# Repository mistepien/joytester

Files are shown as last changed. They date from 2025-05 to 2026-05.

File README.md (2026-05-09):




# joytester
Joytester for testing of Atari-like+ joysticks

Joytester for testing Atari-like joysticks -- tests also FIRE2 nd FIRE3 in C64 and Amiga/Atari mode.

More about Amiga/Atari and C64 modes: <a href="https://wiki.icomp.de/wiki/File:JoystickMod.jpg">schematic of universal joystick</a>.

<b>Populate only one of U1 or U2, never both!</b>

SW3 is redundand.

You can use the <a href="https://github.com/mistepien/joytester/tree/main/production">gerber file</a> to order the PCB.

Here you have <a href="https://github.com/mistepien/joytester/blob/main/joytester.pdf
">the schematic file</a> to find out how does it work.

BOM:
| Qty	| Reference(s) | Description |
|-----|---|---|
|10 | D1, D2, D3, D4, D5, D6, D7, D8, D9, D10 | LEDs 3mm |  
|10 | R1, R2, R3, R4, R5, R6, R7, R8, R9, R10 | resisors for D1...D10 |
|3 | R11, R12, R13 | 10KΩ pull-up/pull-down resistors |
| 2 | R14, R15 | 5K1Ω resistors for J3 USB C power-only socket |
|1 | J1| DB9 Male Connector ( eg. <a href="https://www.tme.eu/pl/en/details/ld09p13a4gx00lf/d-sub-plugs-and-sockets/amphenol-communications-solutions/">LD09P13A4GX00LF Amphenol</a>) |
|1 | J2 | USB B socket |
|1 | J3 | USB C power-only socket (eg.  <a href="https://www.tme.eu/pl/en/details/usb4125-gf-a/usb-ieee1394-connectors/gct/">USB4125-GF-A GCT</a> ) |
|1 | J4 | USB B Mini socket |
|1 | J5 | USB B Micro socket |
|1 | U1 | DIP14 socket (width 7.62mm) + 4070 IC or 4030 IC XOR Gates|
|1 | U2 | DIP14 socket (width 7.62mm) + 74HC86 IC XOR Gates |
|2| C1, C2 | decoupling capacitors for U2 | 
|2| C3, C4 | decoupling capacitors for U1 | 
|2 | SW1, SW2 | SPDT switches or 3x1 2.54mm pinheaders |
|1 | SW3 | SPDT switch, terminal pitch: 4.7mm |

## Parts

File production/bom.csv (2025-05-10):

Designator | Footprint | Quantity | Value | LCSC Part #
C1, C2, C3, C4 | C_Disc_D3.8mm_W2.6mm_P2.50mm | 4 | 100nF
D1 | LED_D3.0mm_Oval | 1 | C64
D10 | LED_D3.0mm_Oval | 1 | AMIGA
D2 | LED_D3.0mm_Oval | 1 | RIGHT
D3 | LED_D3.0mm_Oval | 1 | UP
D4 | LED_D3.0mm_Oval | 1 | DOWN
D5 | LED_D3.0mm_Oval | 1 | FIRE1
D6 | LED_D3.0mm_Oval | 1 | STATUS
D7 | LED_D3.0mm_Oval | 1 | LEFT
D8 | LED_D3.0mm_Oval | 1 | FIRE2
D9 | LED_D3.0mm_Oval | 1 | FIRE3
J1 | DSUB-9_Male_Horizontal_P2.77x2.84mm_EdgePinOffset7.70mm_Housed_MountingHolesOffset9.12mm | 1 | DB9_Male
J2 | USB_B_Lumberg_2411_02_Horizontal_Oval_Versatile | 1 | USB_B
J3 | GCT_USB4125-GF-A | 1 | USB_C_Receptacle_PowerOnly_6P
J4 | UBM5BRDM144DLFSNL | 1 | USB_B_Mini
J5 | USB_Micro-B_Amphenol_10118194_Horizontal | 1 | USB_B_Micro
R1, R10, R2, R3, R4, R5, R6, R7, R8, R9 | R_Axial_DIN0207_L6.3mm_D2.5mm_P10.16mm_Horizontal_Oval | 10 | RxΩ
R11, R12, R13 | R_Axial_DIN0207_L6.3mm_D2.5mm_P10.16mm_Horizontal_Oval | 3 | R10KΩ
R14, R15 | R_Axial_DIN0207_L6.3mm_D2.5mm_P10.16mm_Horizontal_Oval | 2 | R5K1Ω
SW1 | E-Switch-EG1218-Manufacturer_Recommended_Oval | 1 | C64MODESW
SW2 | E-Switch-EG1218-Manufacturer_Recommended_Oval | 1 | POWER
SW3 | 100SP1T1B4M2QE | 1 | POWER
U1 | DIP-14_W7.62mm_Socket_LongPads | 1 | 4070
U2 | DIP-14_W7.62mm_Socket_LongPads | 1 | 74HC86

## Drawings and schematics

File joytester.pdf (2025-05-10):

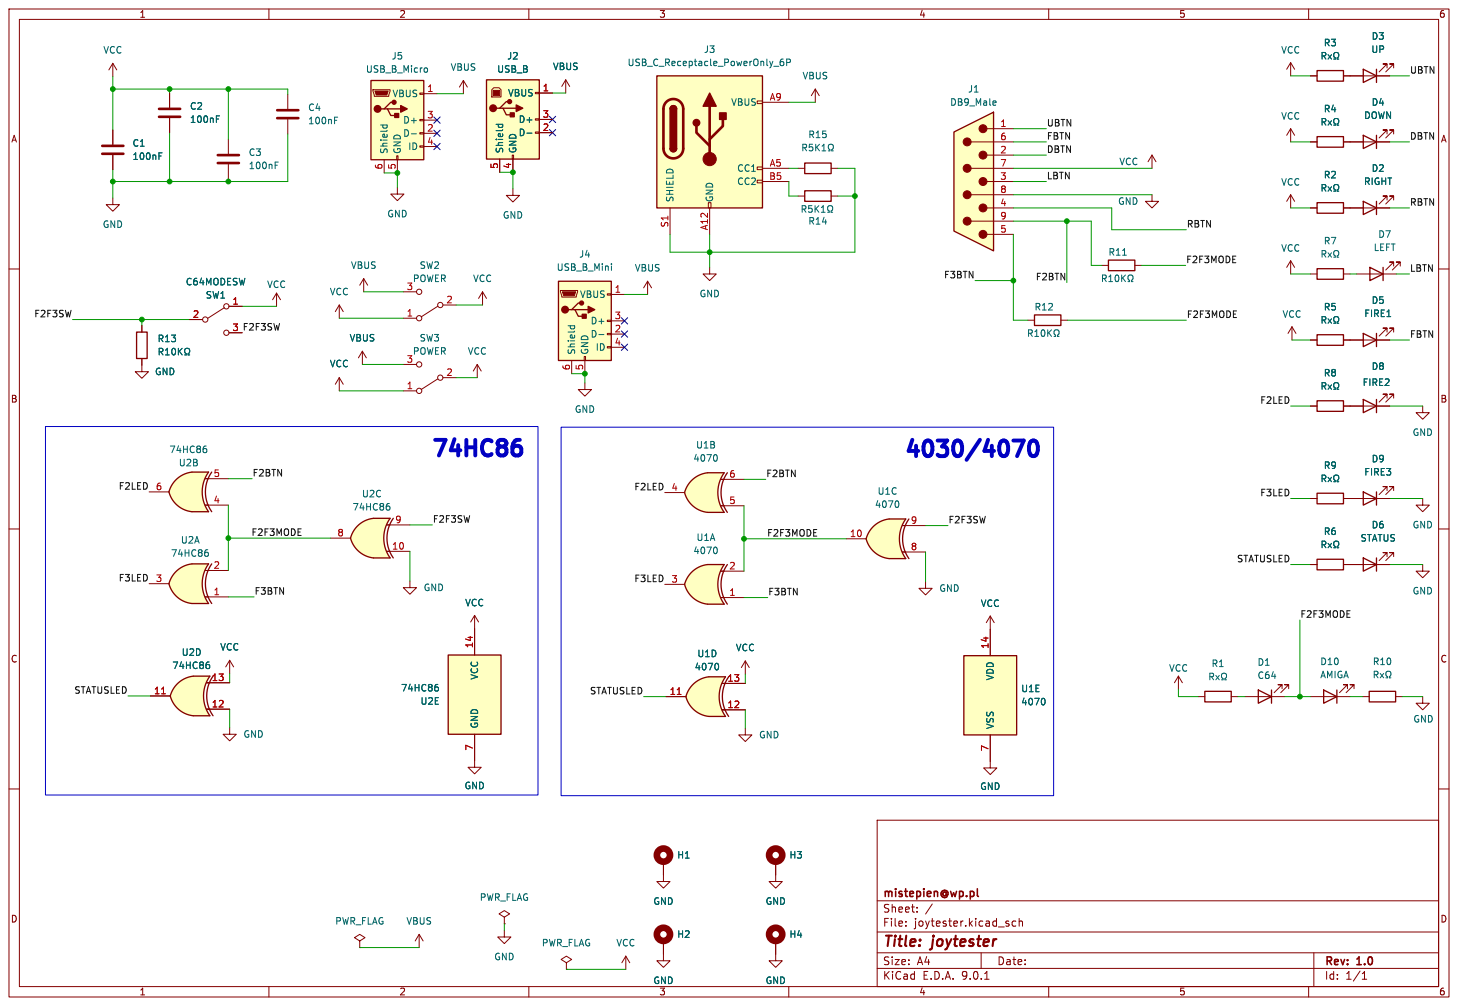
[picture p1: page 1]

þÿRx© GND GND GND

Id: 1/1 Title: joytester File: joytester.kicad_sch Sheet: / mistepien@wp.pl GND
GND

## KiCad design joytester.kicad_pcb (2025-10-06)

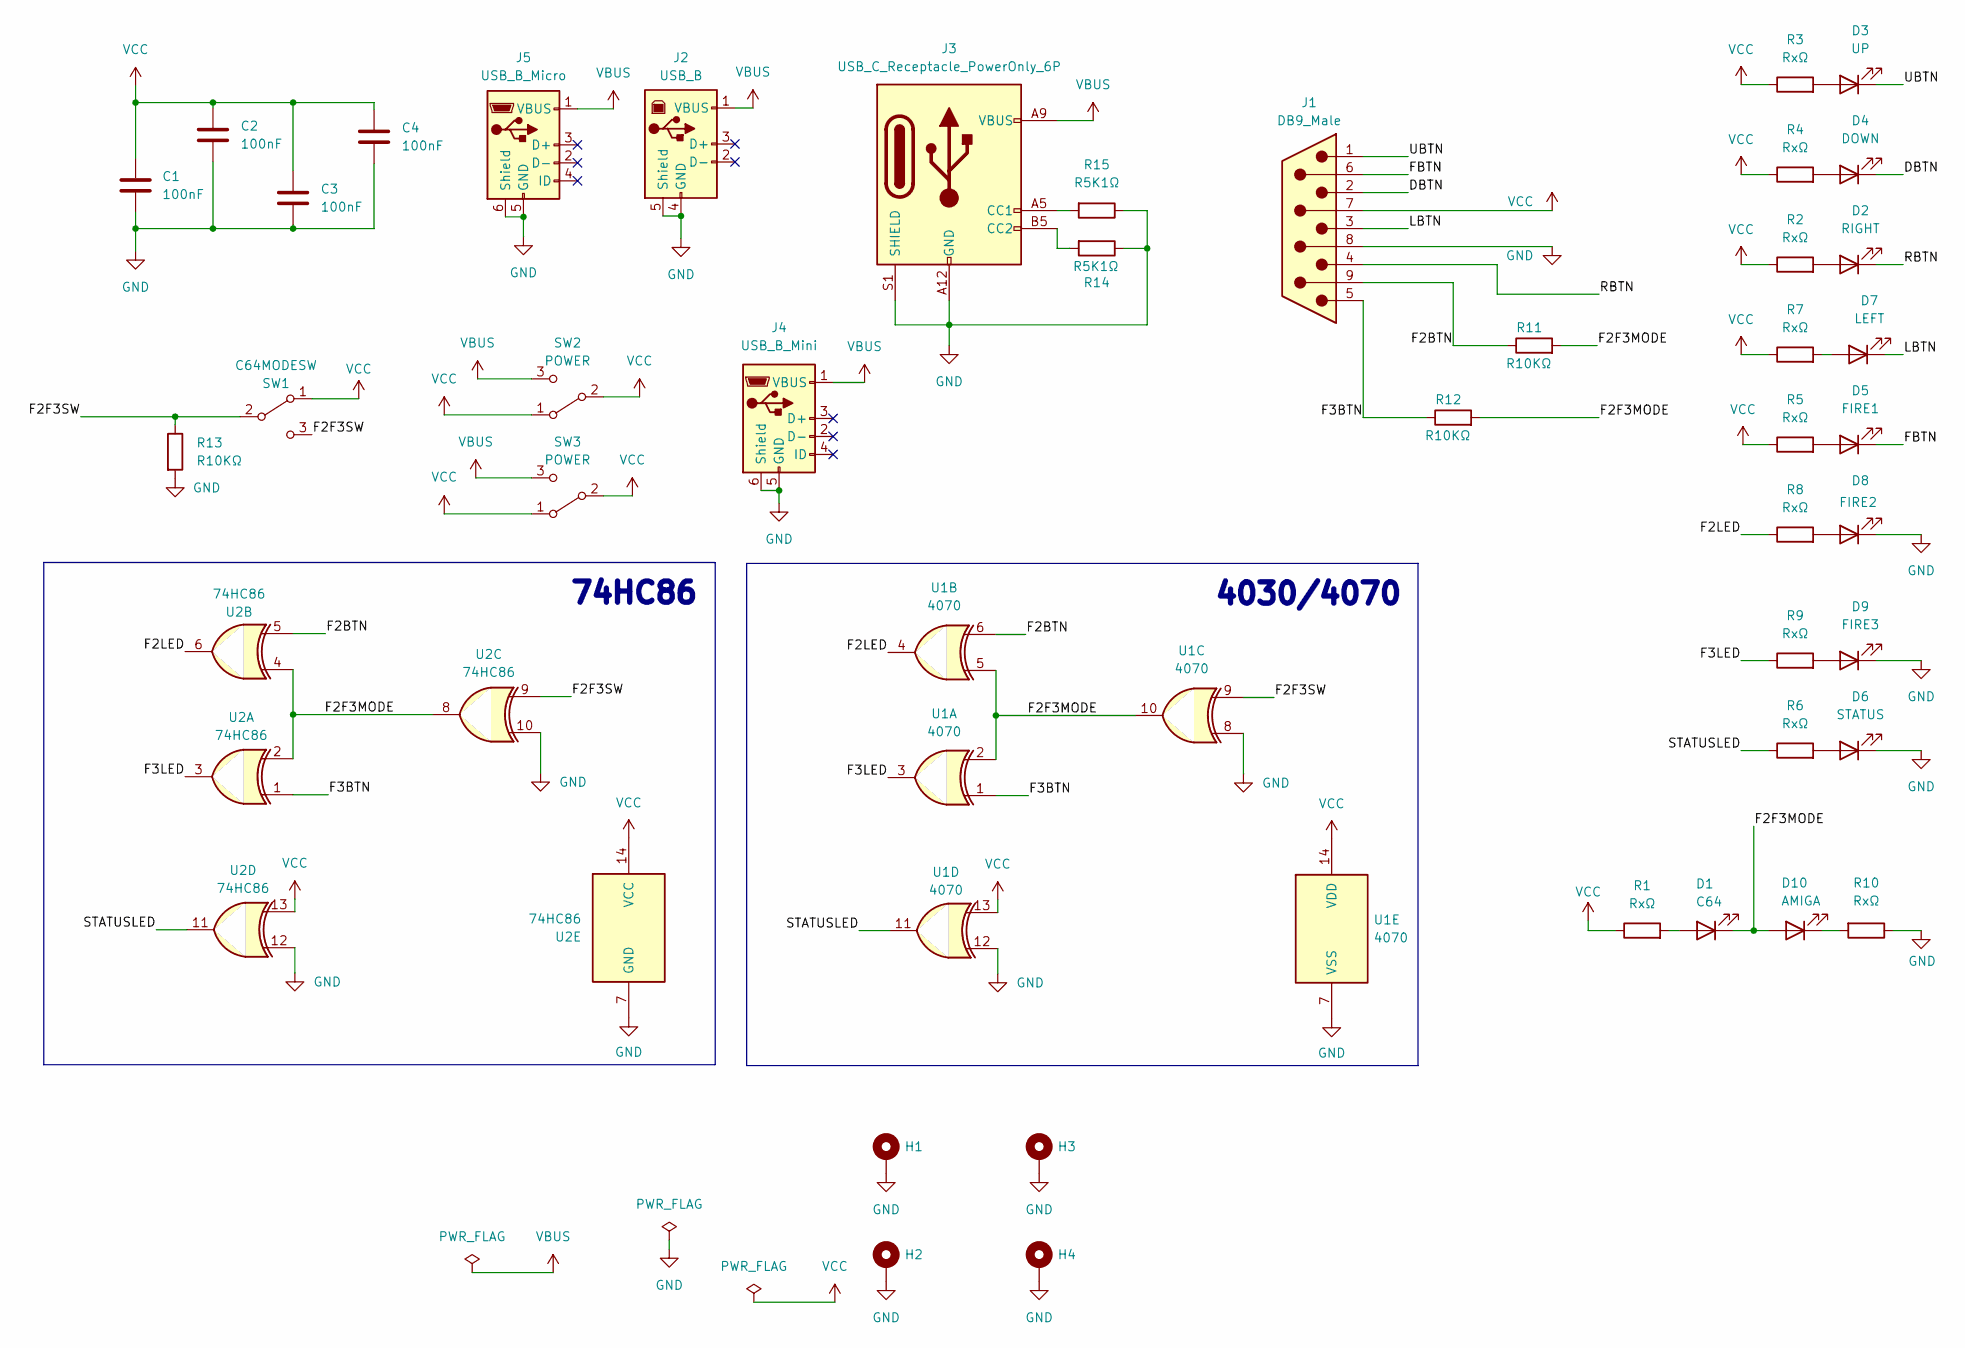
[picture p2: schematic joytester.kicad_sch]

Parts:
C1, C2, C3, C4: 100nF; C_Disc_D3.8mm_W2.6mm_P2.50mm
D1: C64; LED_D3.0mm_Oval
D2: RIGHT; LED_D3.0mm_Oval
D3: UP; LED_D3.0mm_Oval
D4: DOWN; LED_D3.0mm_Oval
D5: FIRE1; LED_D3.0mm_Oval
D6: STATUS; LED_D3.0mm_Oval
D7: LEFT; LED_D3.0mm_Oval
D8: FIRE2; LED_D3.0mm_Oval
D9: FIRE3; LED_D3.0mm_Oval
D10: AMIGA; LED_D3.0mm_Oval
H1, H2, H3, H4: MountingHole; MountingHole_3.5mm_Pad_Via
J1: DB9_Male; DSUB-9_Male_Horizontal_P2.77x2.84mm_EdgePinOffset7.70mm_Hou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
J2: USB_B; USB_B_Lumberg_2411_02_Horizontal_Oval_Versatile
J3: USB_C_Receptacle_PowerOnly_6P; GCT_USB4125-GF-A
J4: USB_B_Mini; UBM5BRDM144DLFSNL
J5: USB_B_Micro; USB_Micro-B_Amphenol_10118194_Horizontal
R1, R2, R3, R4, R5, R6, R7, R8, R9, R10: RxΩ; R_Axial_DIN0207_L6.3mm_D2.5mm_P10.16mm_Horizontal_Oval
R11, R12, R13: R10KΩ; R_Axial_DIN0207_L6.3mm_D2.5mm_P10.16mm_Horizontal_Oval
R14, R15: R5K1Ω; R_Axial_DIN0207_L6.3mm_D2.5mm_P10.16mm_Horizontal_Oval
SW1: C64MODESW; E-Switch-EG1218-Manufacturer_Recommended_Oval
SW2: POWER; E-Switch-EG1218-Manufacturer_Recommended_Oval
SW3: POWER; 100SP1T1B4M2QE
U1: 4070; DIP-14_W7.62mm_Socket_LongPads
U2: 74HC86; DIP-14_W7.62mm_Socket_LongPads

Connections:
/DBTN: D4.1 (K), J1.2
/F2BTN: J1.9, R11.1, U1.6, U2.5
/F2F3MODE: D1.1 (K), D10.2 (A), R11.2, R12.2, U1.2, U1.5, U1.10, U2.2, U2.4, U2.8
/F2F3SW: R13.1, SW1.2 (B), SW1.3 (C), U1.9, U2.9
/F2LED: R8.1, U1.4, U2.6
/F3BTN: J1.5, R12.1, U1.1, U2.1
/F3LED: R9.1, U1.3, U2.3
/FBTN: D5.1 (K), J1.6
/LBTN: D7.1 (K), J1.3
/RBTN: D2.1 (K), J1.4
/STATUSLED: R6.1, U1.11, U2.11
/UBTN: D3.1 (K), J1.1
GND: C1.2, C2.2, C3.2, C4.2, D6.1 (K), D8.1 (K), D9.1 (K), H1.1, H2.1, H3.1, H4.1, J1.8, J2.4 (GND), J2.5 (Shield), J3.A12 (GND), J3.B12 (GND), J3.S1 (SHIELD), J4.5 (GND), J4.6 (Shield), J5.5 (GND), J5.6 (Shield), R10.1, R13.2, R14.1, R15.1, U1.7 (VSS), U1.8, U1.12, U2.7 (GND), U2.10, U2.12
unnamed: D1.2 (A), R1.2
unnamed: D2.2 (A), R2.2
unnamed: D3.2 (A), R3.2
unnamed: D4.2 (A), R4.2
unnamed: D5.2 (A), R5.2
unnamed: D6.2 (A), R6.2
unnamed: D7.2 (A), R7.2
unnamed: D8.2 (A), R8.2
unnamed: D9.2 (A), R9.2
unnamed: D10.1 (K), R10.2
unnamed: J3.A5 (CC1), R15.2
unnamed: J3.B5 (CC2), R14.2
VBUS: J2.1 (VBUS), J3.A9 (VBUS), J3.B9 (VBUS), J4.1 (VBUS), J5.1 (VBUS), SW2.3 (C), SW3.3 (C)
VCC: C1.1, C2.1, C3.1, C4.1, J1.7, R1.1, R2.1, R3.1, R4.1, R5.1, R7.1, SW1.1 (A), SW2.1 (A), SW2.2 (B), SW3.1 (A), SW3.2 (B), U1.13, U1.14 (VDD), U2.13, U2.14 (VCC)

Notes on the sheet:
74HC86
4030/4070

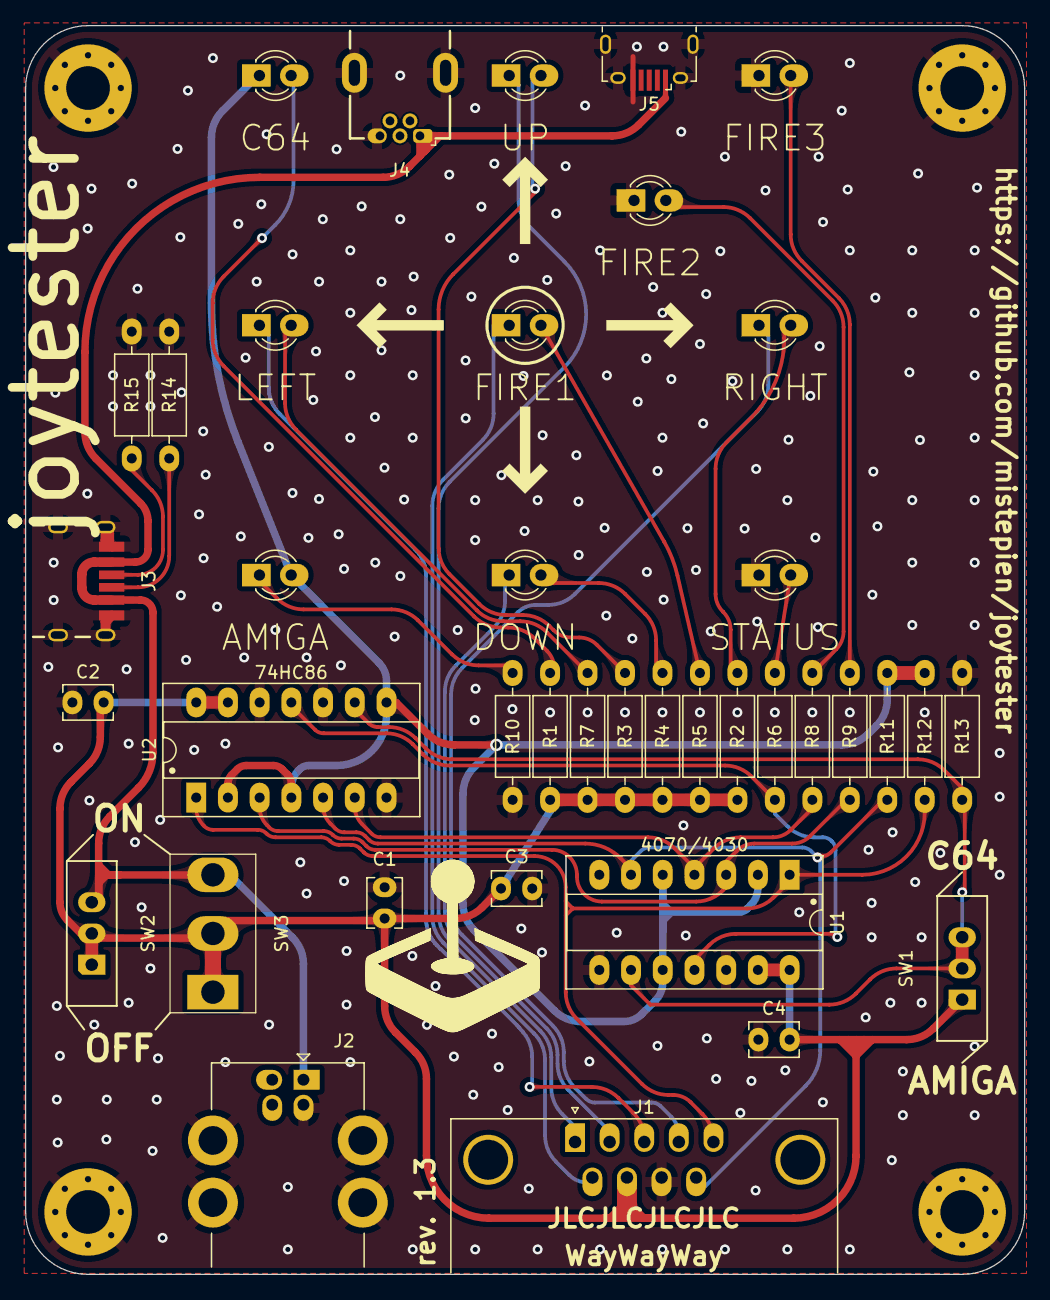
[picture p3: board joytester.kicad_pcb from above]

Board: 2 copper layers, 80.0 x 100.0 mm, 43 parts (0 on the bottom side), 27 nets.

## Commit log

2025-05-10 upload of files
    [bom.csv, designators.csv, joytester.kicad_pcb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]
2025-05-10 upload of schematic
2025-05-10 update of schematic file
2025-09-02 minor update
    [joytester.kicad_pcb]
2025-10-06 update of Micro USB footprint
    [joytester.kicad_pcb, joytester.kicad_sch]
